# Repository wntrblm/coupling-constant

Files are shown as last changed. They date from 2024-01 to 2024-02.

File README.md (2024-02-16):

# Winterbloom Coupling Constant

Coupling Constant is high-quality, transparent guitar buffer.

More details available at https://winterbloom.com/shop/coupling-constant

## Repository layout

This repository contains the hardware design files and user guide for Coupling Constant:

- **factory/** contains the scripts used to program, test, and calibrate the module after assembly. These scripts are all written in Python.
- **hardware/** contains the hardware design files for the mainboard and blank panel, as well as hardware for automated testing. These are all created using KiCAD.
- **user_guide/** contains the user's guide source files. These are written in Markdown and published using MkDocs.

## License and contributing

Coupling Constant is open-source hardware and software, however, licensing a project like this is a little complicated. Please take a chance to review the [LICENSE](LICENSE.md) file.

We welcome contributions! Please read our [Code of Conduct](CODE_OF_CONDUCT.md) first.

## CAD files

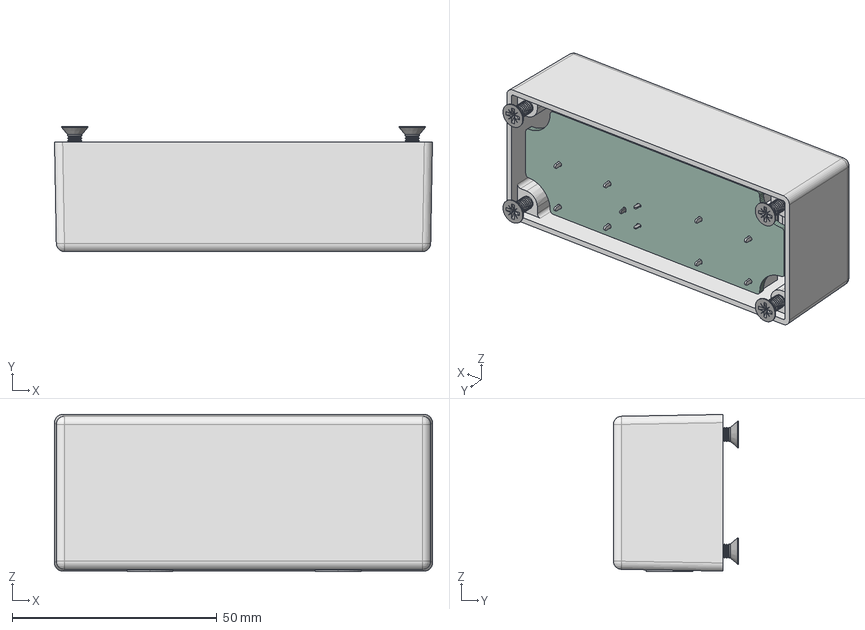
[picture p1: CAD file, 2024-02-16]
hardware/assembly/coupling-constant.FCStd
92.4 x 30.6 x 38.4 mm
27969P BOX
Eddystone Pozi (screw M3.5-0.6X 12mm FH)
Eddystone Pozi (screw M3.5-0.6X 12mm FH)001
Eddystone Pozi (screw M3.5-0.6X 12mm FH)002
Eddystone Pozi (screw M3.5-0.6X 12mm FH)003
coupling-constant PCB

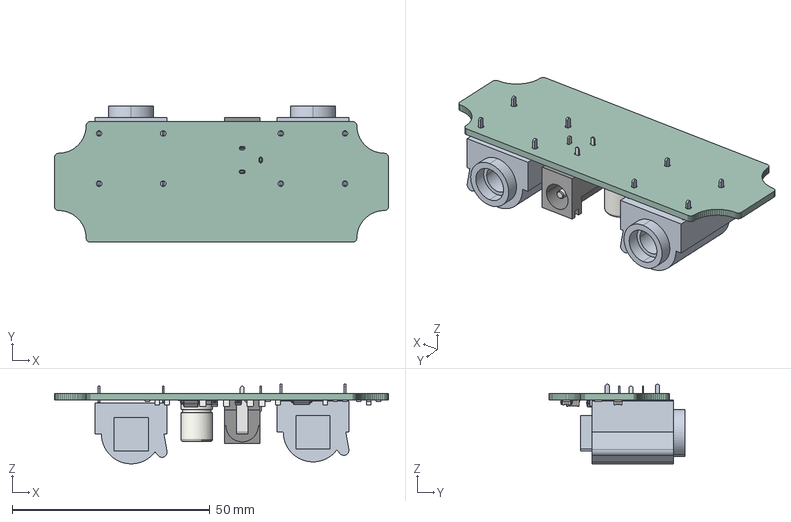
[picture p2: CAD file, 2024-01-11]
hardware/mainboard/coupling-constant.step
84.5 x 34.5 x 20.2 mm
coupling-constant PCB

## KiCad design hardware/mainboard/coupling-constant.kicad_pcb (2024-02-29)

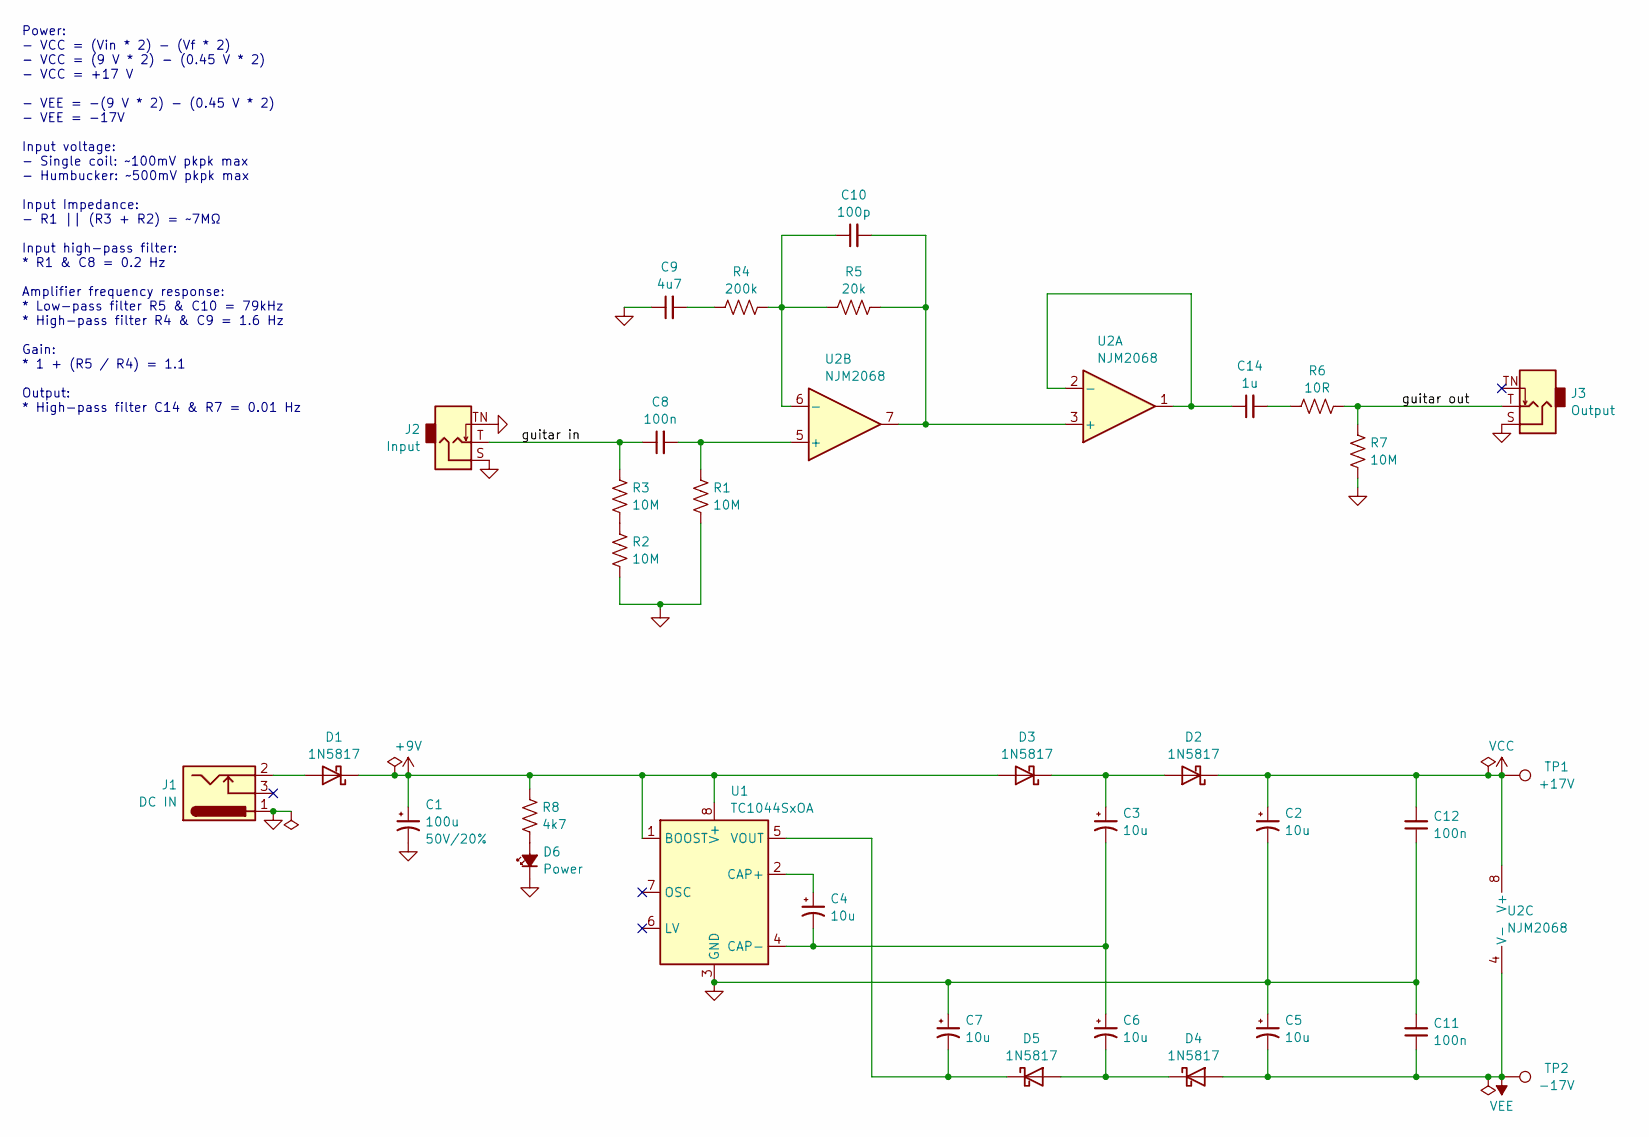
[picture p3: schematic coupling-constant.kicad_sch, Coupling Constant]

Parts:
C1: 100u; CP_Elec_8x10.5; Rating 50V/20%; mpn UUD1V101MNL1GS
C2, C3, C4, C5, C6, C7: 10u; C_1206_HandSolder; Rating 25V/10%; mpn GRM21BR61E106KA73L
C8, C11, C12: 100n; C_0805_HandSolder; Rating 50V/10%; mpn CL21B104KBCNNNC
C9: 4u7; C_0805_HandSolder; Rating 25V/10%; mpn CL21A475KAQNNNE
C10: 100p; C_0805_HandSolder; Rating 25V/5%; mpn CC0805JRNPO9BN101
C14: 1u; C_0805_HandSolder; Rating 25V/10%; mpn CL21A105KBCLNNC
D1, D2, D3, D4, D5: 1N5817; D_SOD-123+SOD-123F; Rating 40V; mpn B5819W
D6: Power; LED_D3.0mm
J1: DC IN; BarrelJack_CUI_PJ-102AH_Horizontal; mpn PJ-102A
J2: Input; Jack_6.35mm_Neutrik_NMJ4HCD2_Horizontal
J3: Output; Jack_6.35mm_Neutrik_NMJ4HCD2_Horizontal
R1, R2, R3, R7: 10M; R_0805_HandSolder; Rating 125mW/10%; mpn RC0805JR-0710ML
R4: 200k; R_0805_HandSolder; Rating 125mW/1%/Thin; mpn RT0805DRD07200KL
R5: 20k; R_0805_HandSolder; Rating 125mW/1%/Thin; mpn RT0805FRE0720KL
R6: 10R; R_0805_HandSolder; Rating 125mW/1%/Thin; mpn RT0805FRE0710RL
R8: 4k7; R_0805_HandSolder; Rating 125mW/1%/Thin; mpn RT0805FRE074K7L
TP1: +17V; TestPoint_Pad_D1.0mm
TP2: -17V; TestPoint_Pad_D1.0mm
U1: TC1044SxOA; SOIC-8_3.9x4.9mm_P1.27mm; mpn TC1044SEOA713
U2: NJM2068; SOIC-8+DMP-8_5mmx5mm_P1.27mm; mpn NJM2068M

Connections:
+9V: C1.1, D1.1 (K), D3.2 (A), R8.2, U1.1 (BOOST), U1.8 (V+)
/guitar in: C8.1, J2.T, R3.1
/guitar out: J3.T, R6.1, R7.2
GND: C1.2, C2.2, C5.1, C7.1, C9.1, C11.2, C12.1, D6.1 (K), J1.1, J2.S, J2.TN, J3.S, R1.2, R2.2, R7.1, U1.3 (GND)
unnamed: C9.2, R4.1
unnamed: C14.2, R6.2
unnamed: D1.2 (A), J1.2
unnamed: C3.1, D2.2 (A), D3.1 (K)
unnamed: C6.2, D4.1 (K), D5.2 (A)
unnamed: C7.2, D5.1 (K), U1.5 (VOUT)
unnamed: D6.2 (A), R8.1
unnamed: R2.1, R3.2
unnamed: C4.1, U1.2 (CAP+)
unnamed: C3.2, C4.2, C6.1, U1.4 (CAP-)
unnamed: C10.2, R5.2, U2.3 (+), U2.7
unnamed: C14.1, U2.1, U2.2 (-)
unnamed: C8.2, R1.1, U2.5 (+)
unnamed: C10.1, R4.2, R5.1, U2.6 (-)
VCC: C2.1, C12.2, D2.1 (K), TP1.1, U2.8 (V+)
VEE: C5.2, C11.1, D4.2 (A), TP2.1, U2.4 (V-)

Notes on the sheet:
Power: - VCC = (Vin * 2) - (Vf * 2) - VCC = (9 V * 2) - (0.45 V * 2) - VCC = +17 V - VEE = -(9 V * 2) - (0.45 V * 2) - VEE = -17V Input voltage: - Single coil: ~100mV pkpk max - Humbucker: ~500mV pkpk max Input Impedance: - R1 || (R3 + R2) = ~7MΩ Input high-pass filter: * R1 & C8 = 0.2 Hz Amplifier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

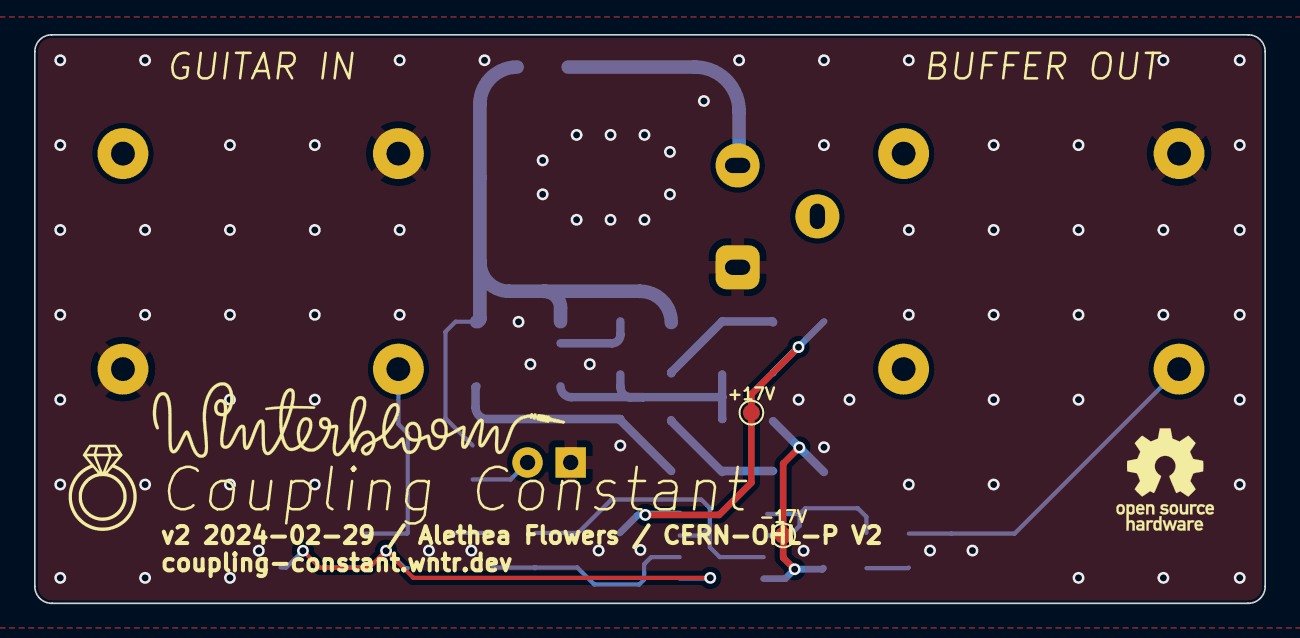
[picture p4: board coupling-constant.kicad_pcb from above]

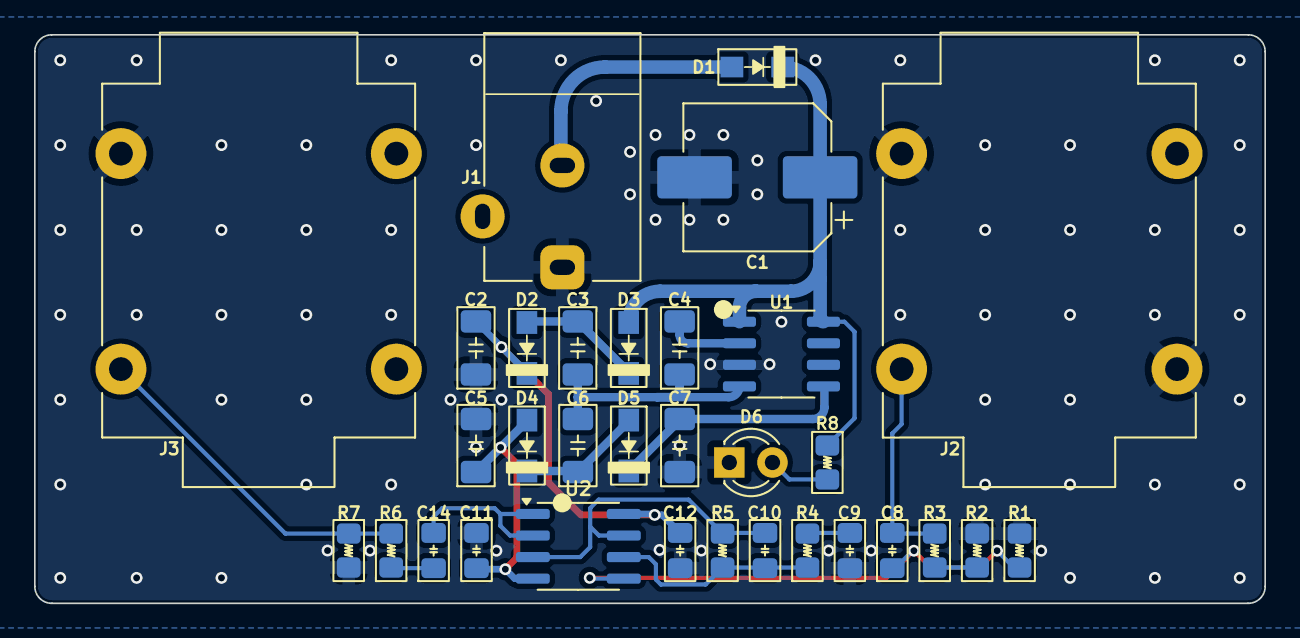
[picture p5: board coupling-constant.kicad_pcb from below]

Board: 2 copper layers, 72.5 x 33.5 mm, 34 parts (32 on the bottom side), 20 nets.

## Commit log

2024-01-11 initial version
    [coupling-constant.kicad_pcb, coupling-constant.kicad_sch, coupling-constant.step]
2024-01-21 v1, fixup op amp inputs
    [coupling-constant.kicad_pcb, coupling-constant.kicad_sch]
2024-02-13 finalize v1
    [coupling-constant.kicad_pcb, coupling-constant.kicad_sch]
2024-02-16 project structure
    [coupling-constant.FCStd, coupling-constant.kicad_pcb, coupling-constant.kicad_sch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]
2024-02-16 fix drawing sheet path
    [coupling-constant.kicad_sch]
2024-02-23 hardware: fix mpn for resistor
    [coupling-constant.kicad_sch]
2024-02-29 hardware: revision 2
    - Swap TL072 for NJM2068
    - Swap footprint for one compatible with SOIC-8 and DMP-8, making it easier to swap op-amps
    - Remove feedback cap in output amplifier, it's not needed and has only caused problems.
    - Update everything to KiCAD 8
    [coupling-constant.kicad_pcb, coupling-constant.kicad_sch]

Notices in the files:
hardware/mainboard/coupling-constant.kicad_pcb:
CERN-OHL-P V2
